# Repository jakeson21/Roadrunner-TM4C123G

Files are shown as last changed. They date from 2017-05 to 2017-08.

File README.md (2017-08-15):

# Roadrunner
Arduino clone based on TI's TM4C123G, an ARM M4F running at 80 MHz.

# Project Goal 
The goal of this project is to build a bridge between Texas Instrument's Tiva™ C LaunchPad, based on the TM4C123GH6PM, and the Arduino form factor. The LaunchPad series of development kits already benefit from an Arduino-like code development environment in the form of Energia, but lack a compatible form factor to make use of the extensive list of shields.

This project aims to merge these two worlds by putting the processing power and integrated peheripherial set of the 80-MHz ARM M4F based TM4C123 series of micro controllers into the Arduino-Leo (and Uno, Duemilanove, Due, *Mega) compatible form factor.
This will provide typical Arduino users with a much more powerful board while maintaining a familiar programming environment (through the use of Energia). It also provides a platform for those wanting to grow beyond this basic development approach into a more low-level IDE by using TI's free Code Composer Studio and selecting the EK-TM4C123GXL project configuration.

*The board breaks out all pins, but only utilizes the basic set of headers to maintain a 2" x 3" form factor.

# Other notable parameters
Most GPIO are 5V tolerant
Peripheral libraries are pre-loaded onto on-board ROM, reducing support code size.
32-bit CPU with single-precision FPU
Single-cycle multiply instruction and hardware divide
16-bit SIMD vector processing unit
Ultra-low power consumption with integrated sleep modes
etc... See datasheet for more information

# Project Planning
✔ Circuit design (using KiCAD). Programming will rely on the use of an EK-TM4C123GXL dev kit by tapping into its target ICDI JTAG headers.

✔ Board layout, including relocating Energia defined pins to their Arduino form factor locations.

✔ Fabrication (sent to OSH Park 4/16/2017)

✔ Board assembly

✔ Create custom board definition for use in Energia

▢ Hardware testing and verification

▢ Mass-production if enough people are interested

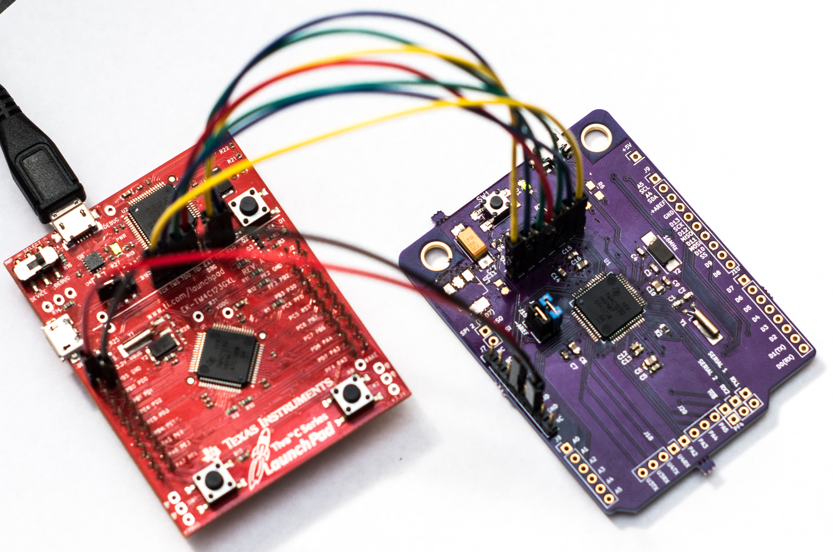
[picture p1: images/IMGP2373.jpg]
board image


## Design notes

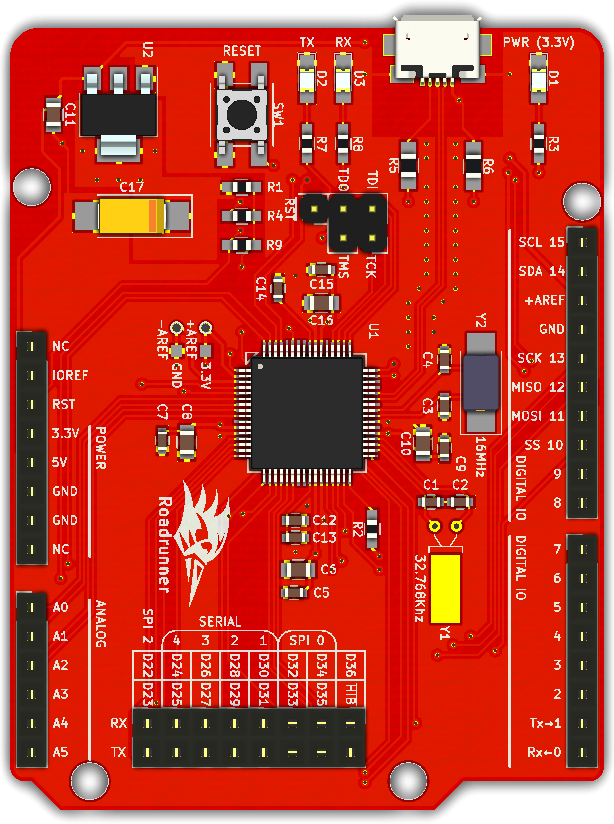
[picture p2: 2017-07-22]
images/Roadrunner_top_v1.1.png

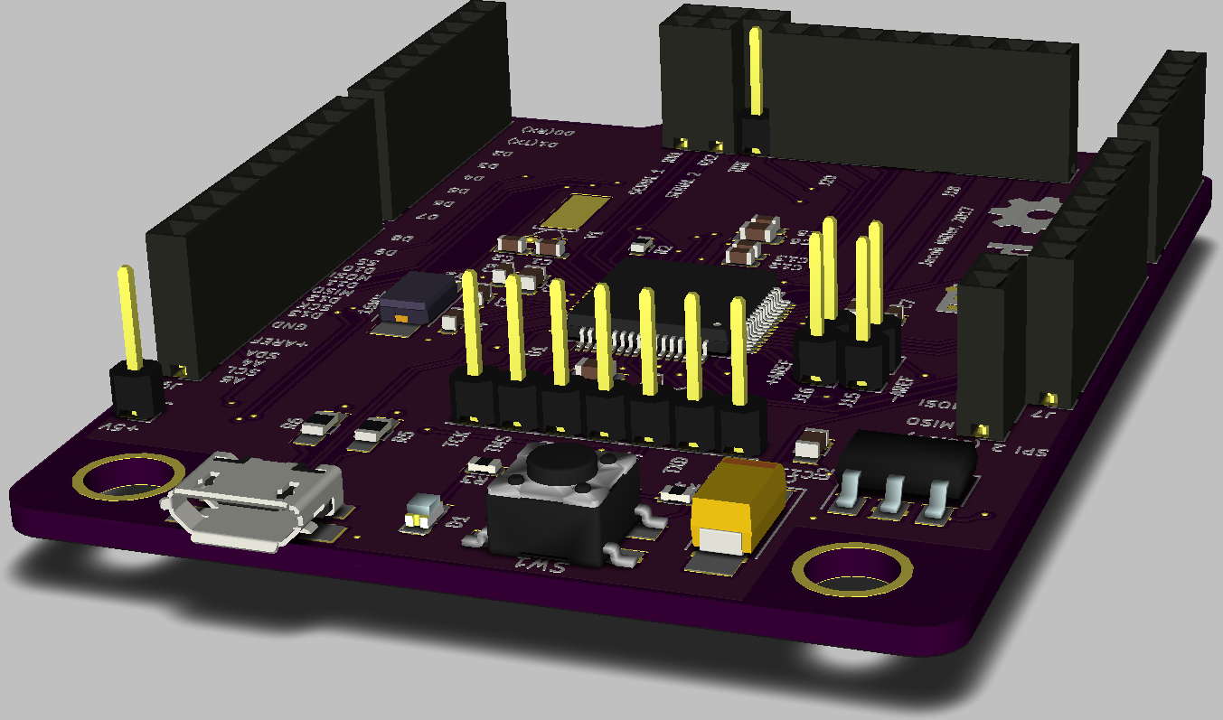
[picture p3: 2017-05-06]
images/Arduino_Leo_Tiva_HiFi_45_osh.png

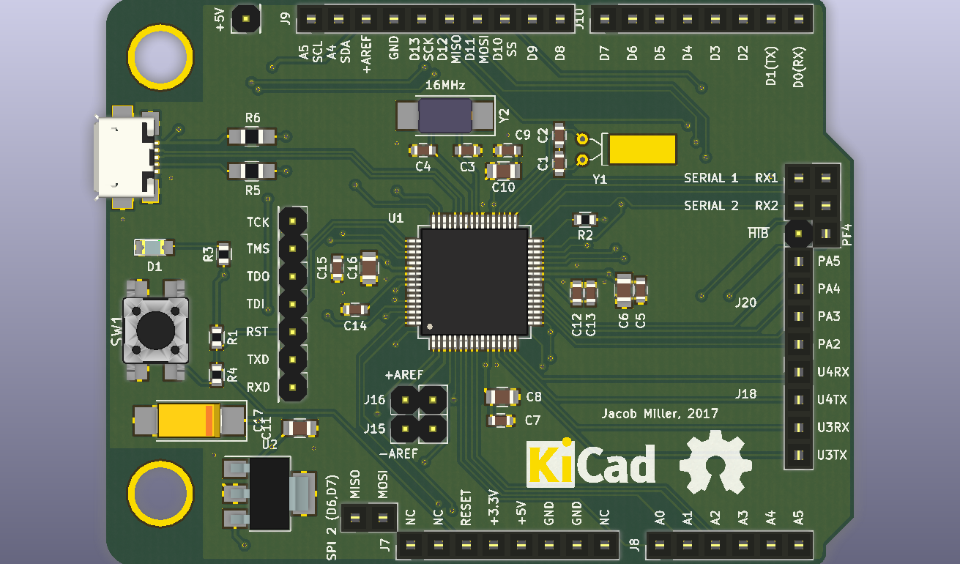
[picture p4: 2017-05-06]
images/Arduino_Leo_Tiva_HiFi_ortho.png

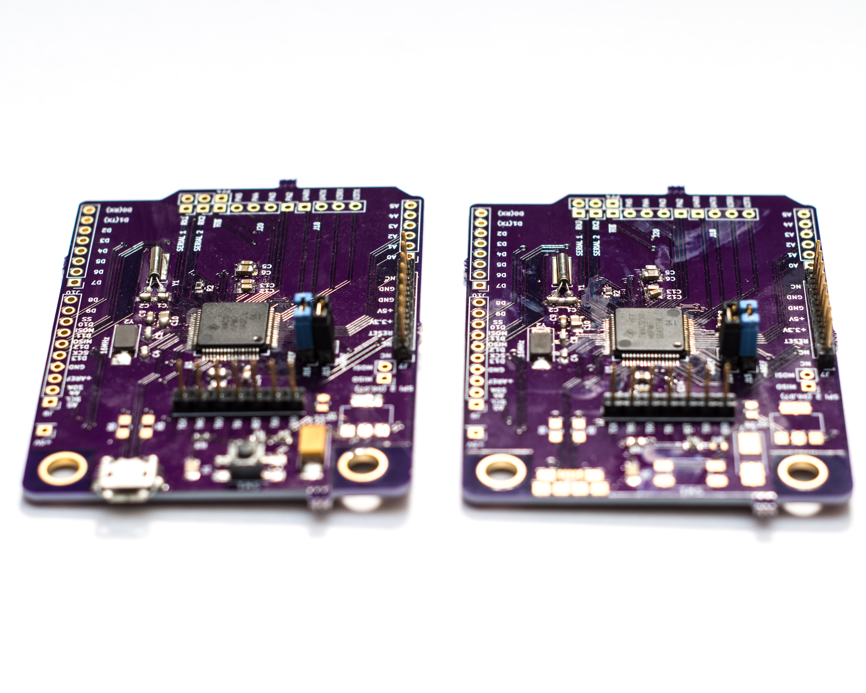
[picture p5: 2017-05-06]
images/IMGP2375.jpg

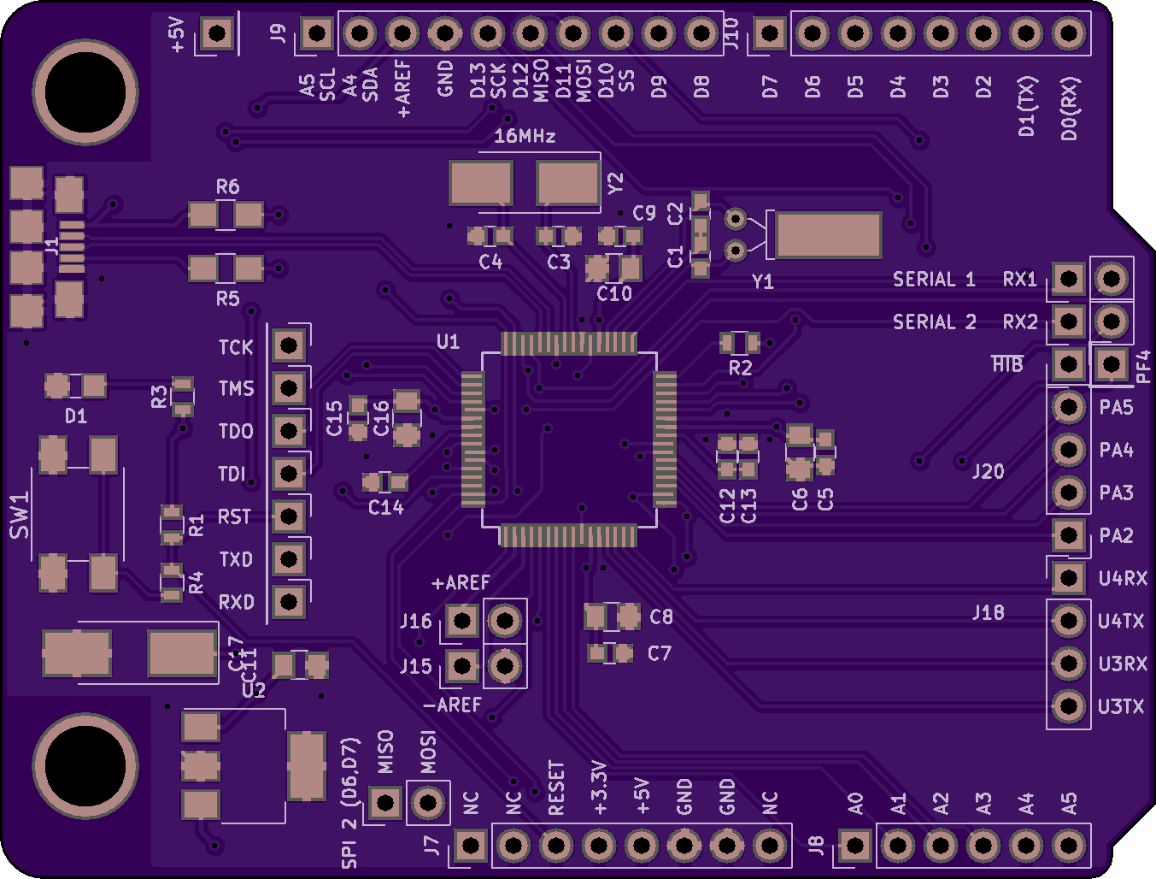
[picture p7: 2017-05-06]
images/osh-park-top.png

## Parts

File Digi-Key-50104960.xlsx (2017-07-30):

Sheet: Sheet1
Index | Quantity | Part Number | Manufacturer Part Number | Description | Customer Reference | Backorder | Unit Price | Extended Price | BOM | Extended Price
1 | 10 | LM1117IMPX-3.3/NOPBCT-ND | LM1117IMPX-3.3/NOPB | IC REG LDO 3.3V 0.8A SOT223 |  | 0 | $0.9270 | $9.27 | 1 | $0.93
2 | 3 | 609-4613-1-ND | 10118192-0001LF | CONN USB MICRO B RECPT SMT R/A |  | 0 | $0.4600 | $1.38 | 1 | $0.46
3 | 10 | 1276-6780-1-ND | CL21A226MOCLRNC | CAP CER 22UF 16V X5R 0805 |  | 0 | $0.1680 | $1.68 | 4 | $0.67
4 | 10 | 490-3296-1-ND | GRM188R61C225KE15D | CAP CER 2.2UF 16V X5R 0603 |  | 0 | $0.0890 | $0.89 | 1 | $0.09
5 | 10 | 475-1410-1-ND | LG R971-KN-1 | LED GREEN DIFFUSED 0805 SMD |  | 0 | $0.1800 | $1.80 | 1 | $0.18
6 | 25 | P10.0KHCT-ND | ERJ-3EKF1002V | RES SMD 10K OHM 1% 1/10W 0603 |  | 0 | $0.0144 | $0.36 | 1 | $0.01
7 | 25 | P1.00MHCT-ND | ERJ-3EKF1004V | RES SMD 1M OHM 1% 1/10W 0603 |  | 0 | $0.0144 | $0.36 | 1 | $0.01
8 | 25 | P100HCT-ND | ERJ-3EKF1000V | RES SMD 100 OHM 1% 1/10W 0603 |  | 0 | $0.0144 | $0.36 | 1 | $0.01
9 | 25 | P75.0HCT-ND | ERJ-3EKF75R0V | RES SMD 75 OHM 1% 1/10W 0603 |  | 0 | $0.0144 | $0.36 | 1 | $0.01
10 | 25 | P51.0HCT-ND | ERJ-3EKF51R0V | RES SMD 51 OHM 1% 1/10W 0603 |  | 0 | $0.0144 | $0.36 | 0 | $0.00
11 | 5 | 732-7003-1-ND | 430181038816 | SWITCH TACTILE SPST-NO 0.05A 12V |  | 0 | $0.3500 | $1.75 | 1 | $0.35
12 | 3 | 300-8763-ND | CFS-20632768HZFB | CRYSTAL 32.7680KHZ 12.5PF T/H |  | 0 | $0.6000 | $1.80 | 1 | $0.60
13 | 3 | 644-1187-1-ND | NX5032GA-16MHZ-STD-CSK-4 | CRYSTAL 16.0000MHZ 8PF SMD |  | 0 | $0.7200 | $2.16 | 1 | $0.72
14 | 3 | 399-3744-1-ND | T491C226K016AT | CAP TANT 22UF 16V 10% 2413 |  | 0 | $0.6600 | $1.98 | 1 | $0.66
15 | 10 | 311-1772-1-ND | CC0603JRNPO9BN240 | CAP CER 24PF 50V C0G/NPO 0603 |  | 0 | $0.0650 | $0.65 | 2 | $0.13
16 | 25 | 399-1049-1-ND | C0603C100J5GACTU | CAP CER 10PF 50V C0G/NP0 0603 |  | 0 | $0.0240 | $0.60 | 2 | $0.05
17 | 25 | 311-1777-1-ND | CC0603JRX7R8BB104 | CAP CER 0.1UF 25V X7R 0603 |  | 0 | $0.0232 | $0.58 | 5 | $0.12
18 | 25 | 490-1536-1-ND | GRM188R61C105KA93D | CAP CER 1UF 16V X5R 0603 |  | 0 | $0.0272 | $0.68 | 1 | $0.03
 |  |  |  |  |  |  | Subtotal | $27.02
 |  |  | TM4C123GH6PMI7 | IC MCU 32BIT 256KB FLASH 64LQFP |  |  | $10.67 | $32.01 | 1 | $10.67
 |  |  |  |  |  |  |  |  |  | Component Subtotal per board
 |  |  |  |  |  |  |  |  |  | $15.71
 |  |  | Fabrication | Description | Quantity | Extended Cost |  |  |  | Cost per board built
 |  |  | OSH-Park | 2.71x2.06 inch (68.73x52.22 mm) 4 layer board. | 3 | $55.60 |  |  |  | $34.24

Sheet: BOM
Manufacturer Part Number | BOM | Unit Price | Extended Price
LM1117IMPX-3.3/NOPB | 1 | $0.9270 | $0.93
10118192-0001LF | 1 | $0.4600 | $0.46
CL21A226MOCLRNC | 4 | $0.1680 | $0.67
GRM188R61C225KE15D | 1 | $0.0890 | $0.09
LG R971-KN-1 | 1 | $0.1800 | $0.18
ERJ-3EKF1002V | 1 | $0.0144 | $0.01
ERJ-3EKF1004V | 1 | $0.0144 | $0.01
ERJ-3EKF1000V | 1 | $0.0144 | $0.01
ERJ-3EKF75R0V | 1 | $0.0144 | $0.01
ERJ-3EKF51R0V | 0 | $0.0144 | $0.00
430181038816 | 1 | $0.3500 | $0.35
CFS-20632768HZFB | 1 | $0.6000 | $0.60
NX5032GA-16MHZ-STD-CSK-4 | 1 | $0.7200 | $0.72
T491C226K016AT | 1 | $0.6600 | $0.66
CC0603JRNPO9BN240 | 2 | $0.0650 | $0.13
C0603C100J5GACTU | 2 | $0.0240 | $0.05
CC0603JRX7R8BB104 | 5 | $0.0232 | $0.12
GRM188R61C105KA93D | 1 | $0.0272 | $0.03
TM4C123GH6PMI7 | 1 | $10.67 | $10.67
 |  |  | $15.71

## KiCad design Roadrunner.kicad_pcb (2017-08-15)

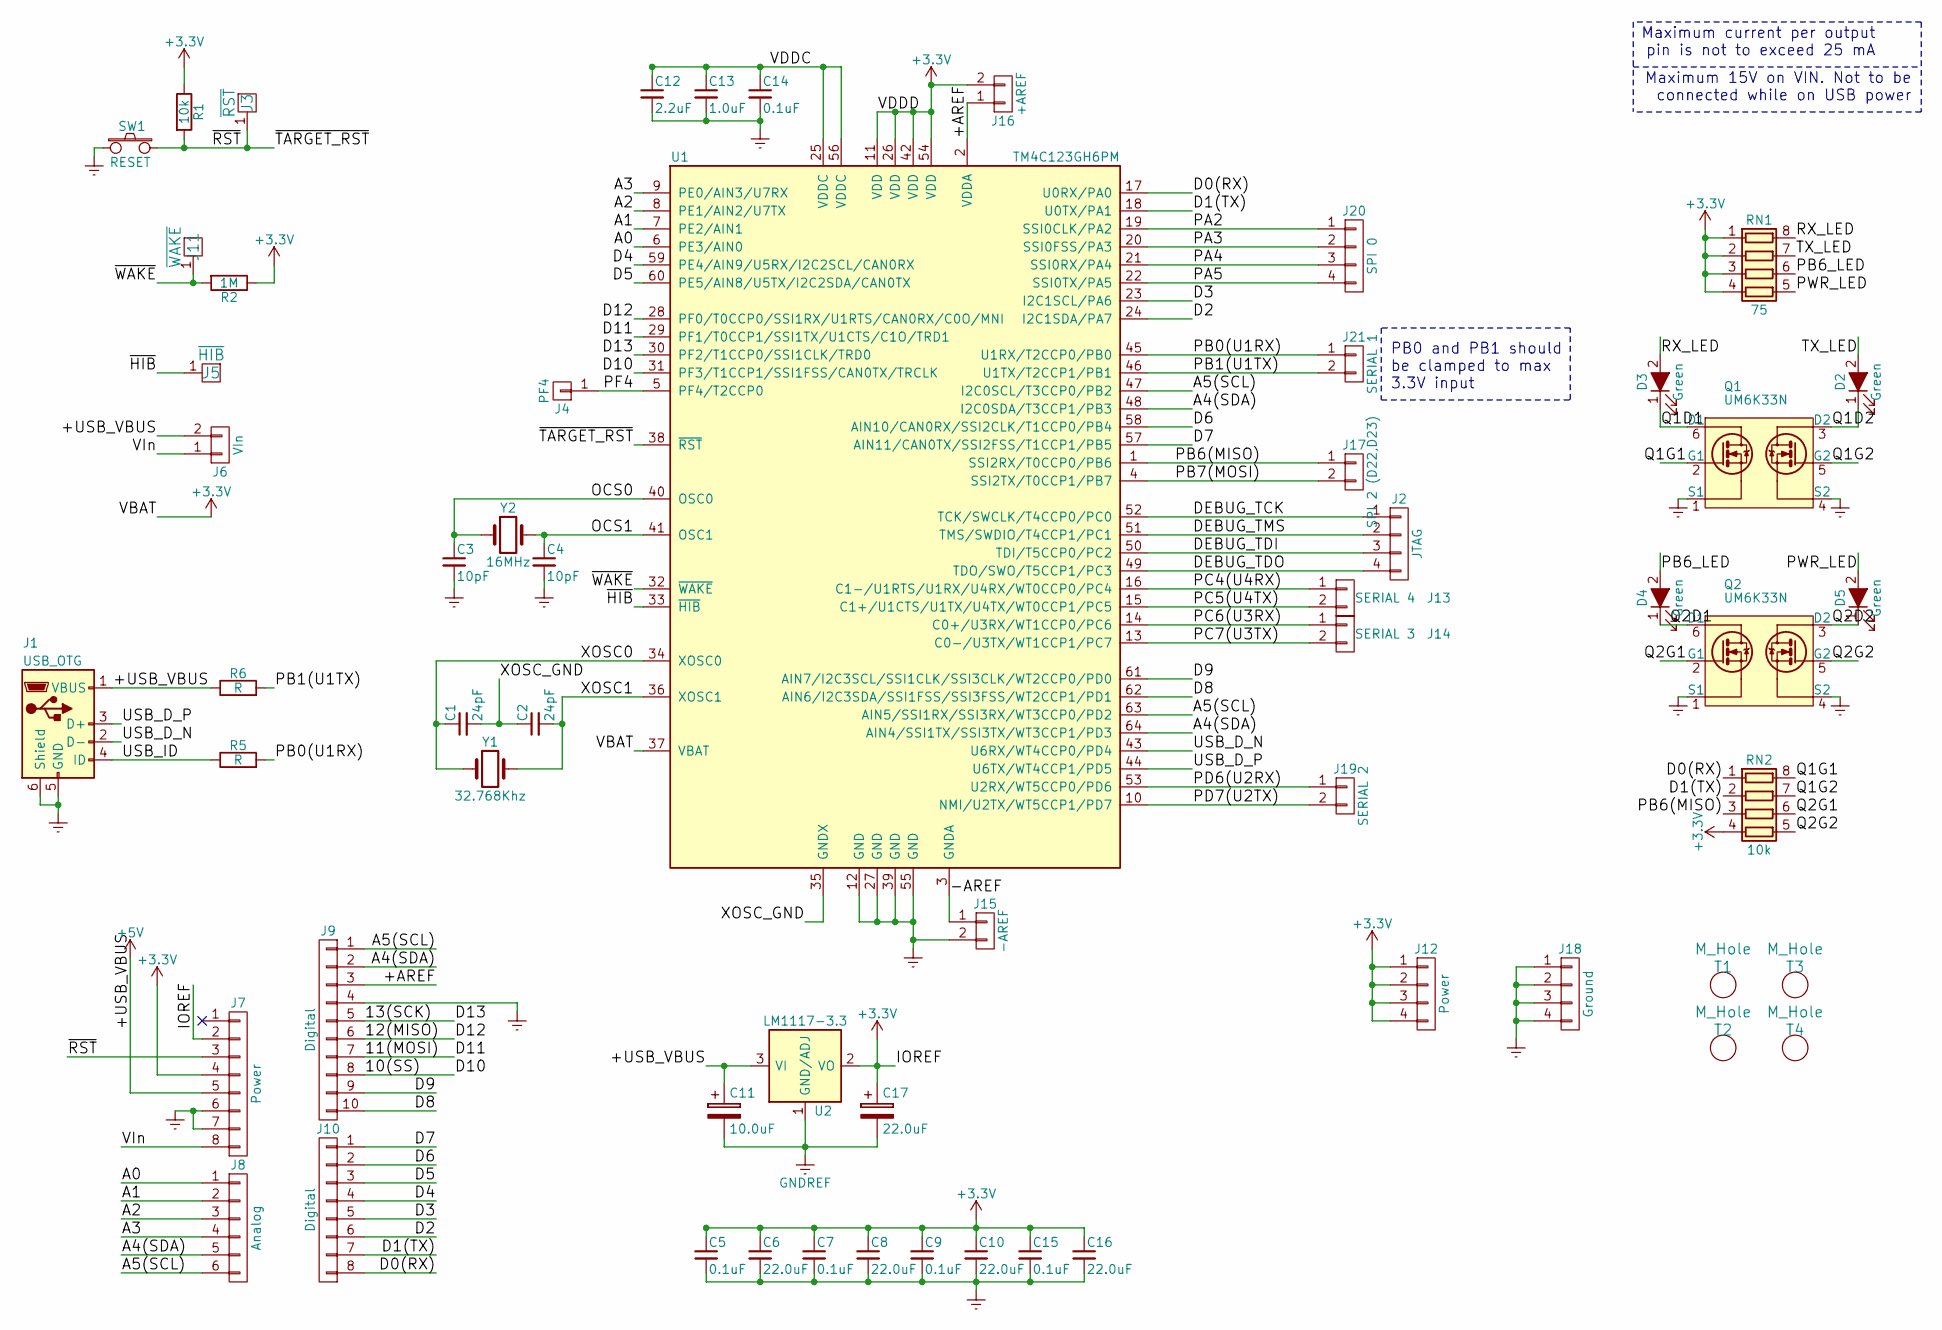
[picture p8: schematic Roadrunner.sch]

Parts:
C1, C2: 24pF; C_0603; Part # CC0603JRNPO9BN240
C3, C4: 10pF; C_0603; Part # C0603C100J5GACTU
C5, C7, C9, C14, C15: 0.1uF; C_0603; Part # CC0603JRX7R8BB104
C6, C8, C10, C16: 22.0uF; C_0805; Part # CL21A226MOCLRNC
C11: 10.0uF; C_0805
C12: 2.2uF; C_0603; Part # GRM188R61C225KE15D
C13: 1.0uF; C_0603; Part # GRM188R61C105KA93D
C17: 22.0uF; CP_Tantalum_Case-C_EIA-6032-28_Hand; Part # T491C226K016AT
D2, D3, D4, D5: Green; LED_0805; Part # LG R971-KN-1
J1: USB_OTG; USB_Micro_B_FCI_10118192; Part # 10118192-0001LF
J2: JTAG; Pin_Header_Straight_2x02_Pitch2.54mm
J3: ~RST; Pin_Header_Straight_1x01_Pitch2.54mm
J4: PF4; Socket_Strip_Straight_1x01_Pitch2.54mm
J5: ~HIB; Socket_Strip_Straight_1x01_Pitch2.54mm
J6: VIn; NetTie-I_Connected_SMD
J7: Power; Socket_Strip_Straight_1x08_Pitch2.54mm
J8: Analog; Socket_Strip_Straight_1x06_Pitch2.54mm
J9: Digital; Socket_Strip_Straight_1x10_Pitch2.54mm
J10: Digital; Socket_Strip_Straight_1x08_Pitch2.54mm
J11: ~WAKE; Socket_Strip_Straight_1x01_Pitch2.54mm
J12: Power; Socket_Strip_Straight_1x04_Pitch2.54mm
J13: SERIAL 4; Socket_Strip_Straight_1x02_Pitch2.54mm
J14: SERIAL 3; Socket_Strip_Straight_1x02_Pitch2.54mm
J15: -AREF; NetTie-I_Connected_SMD
J16: +AREF; NetTie-I_Connected_SMD
J17: SPI 2 (D22,D23); Socket_Strip_Straight_1x02_Pitch2.54mm
J18: Ground; Socket_Strip_Straight_1x04_Pitch2.54mm
J19: SERIAL 2; Socket_Strip_Straight_1x02_Pitch2.54mm
J20: SPI 0; Socket_Strip_Straight_2x02_Pitch2.54mm
J21: SERIAL 1; Socket_Strip_Straight_1x02_Pitch2.54mm
Q1, Q2: UM6K33N; SOT-363_SC-70-6; Part # UM6K33NTN
R1: 10k; R_0603_HandSoldering; Part # RC0603FR-0710KL
R2: 1M; R_0603_HandSoldering; Part # RCG06031M00FKEA
R5, R6: R; R_0805_HandSoldering
RN1: 75; YC164-JR-0775RL; Part # YC164-JR-0775RL
RN2: 10k; YC164-JR-0775RL; Part # EXB-38V103JV
SW1: RESET; SW_SPST_WS-TASV_4.5x4.5mm; Part # 430181038816
T1, T2, T3, T4: M_Hole; ArduinoMountingHole_3.2mm
U1: TM4C123GH6PM; LQFP-64_10x10mm_Pitch0.5mm; Part # TM4C123GH6PMI7
U2: LM1117-3.3; SOT-223; Part # LM1117IMPX-3.3/NOPB
Y1: 32.768Khz; Crystal_C26-LF_d2.1mm_l6.5mm_Horizontal_1EP_style1; Part # CFS-20632768HZFB
Y2: 16MHz; Crystal_SMD_5032-2pin_5.0x3.2mm_HandSoldering; Part # NX5032GA-16MHZ-STD-CSK-4

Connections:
+3V3: C5.1, C6.1, C7.1, C8.1, C9.1, C10.1, C15.1, C16.1, C17.1, J7.2, J7.4, J12.1, J12.2, J12.3, J12.4, J16.2, R1.1, R2.1, RN1.1 (R1.1), RN1.2 (R2.1), RN1.3 (R3.1), RN1.4 (R4.1), RN2.4 (R4.1), U1.11 (VDD), U1.26 (VDD), U1.37 (VBAT), U1.42 (VDD), U1.54 (VDD), U2.2 (VO), U2.4 (VO)
+5V: C11.1, J1.1 (VBUS), J6.2, J7.5, R6.1, U2.3 (VI)
/10(SS): J9.8, U1.31 (PF3/T1CCP1/SSI1FSS/CAN0TX/TRCLK)
/11(MOSI): J9.7, U1.29 (PF1/T0CCP1/SSI1TX/U1CTS/C1O/TRD1)
/12(MISO): J9.6, U1.28 (PF0/T0CCP0/SSI1RX/U1RTS/CAN0RX/C0O/MNI)
/13(SCK): J9.5, U1.30 (PF2/T1CCP0/SSI1CLK/TRD0)
/+AREF: J9.3, J16.1, U1.2 (VDDA)
/-AREF: J15.1, U1.3 (GNDA)
/A0: J8.1, U1.6 (PE3/AIN0)
/A1: J8.2, U1.7 (PE2/AIN1)
/A2: J8.3, U1.8 (PE1/AIN2/U7TX)
/A3: J8.4, U1.9 (PE0/AIN3/U7RX)
/A4(SDA): J8.5, J9.2, U1.48 (I2C0SDA/T3CCP1/PB3), U1.64 (AIN4/SSI1TX/SSI3TX/WT3CCP1/PD3)
/A5(SCL): J8.6, J9.1, U1.47 (I2C0SCL/T3CCP0/PB2), U1.63 (AIN5/SSI1RX/SSI3RX/WT3CCP0/PD2)
/D0(RX): J10.8, RN2.1 (R1.1), U1.17 (U0RX/PA0)
/D1(TX): J10.7, RN2.2 (R2.1), U1.18 (U0TX/PA1)
/D2: J10.6, U1.24 (I2C1SDA/PA7)
/D3: J10.5, U1.23 (I2C1SCL/PA6)
/D4: J10.4, U1.59 (PE4/AIN9/U5RX/I2C2SCL/CAN0RX)
/D5: J10.3, U1.60 (PE5/AIN8/U5TX/I2C2SDA/CAN0TX)
/D6: J10.2, U1.58 (AIN10/CAN0RX/SSI2CLK/T1CCP0/PB4)
/D7: J10.1, U1.57 (AIN11/CAN0TX/SSI2FSS/T1CCP1/PB5)
/D8: J9.10, U1.62 (AIN6/I2C3SDA/SSI1FSS/SSI3FSS/WT2CCP1/PD1)
/D9: J9.9, U1.61 (AIN7/I2C3SCL/SSI1CLK/SSI3CLK/WT2CCP0/PD0)
/DEBUG_TCK: J2.1, U1.52 (TCK/SWCLK/T4CCP0/PC0)
/DEBUG_TDI: J2.3, U1.50 (TDI/T5CCP0/PC2)
/DEBUG_TDO: J2.4, U1.49 (TDO/SWO/T5CCP1/PC3)
/DEBUG_TMS: J2.2, U1.51 (TMS/SWDIO/T4CCP1/PC1)
/OCS0: C3.1, U1.40 (OSC0), Y2.1
/OCS1: C4.1, U1.41 (OSC1), Y2.2
/PA2: J20.1, U1.19 (SSI0CLK/PA2)
/PA3: J20.2, U1.20 (SSI0FSS/PA3)
/PA4: J20.3, U1.21 (SSI0RX/PA4)
/PA5: J20.4, U1.22 (SSI0TX/PA5)
/PB0(U1RX): J21.1, R5.2, U1.45 (U1RX/T2CCP0/PB0)
/PB1(U1TX): J21.2, R6.2, U1.46 (U1TX/T2CCP1/PB1)
/PB6(MISO): J17.1, RN2.3 (R3.1), U1.1 (SSI2RX/T0CCP0/PB6)
/PB6_LED: D4.2 (A), RN1.6 (R3.2)
/PB7(MOSI): J17.2, U1.4 (SSI2TX/T0CCP1/PB7)
/PC4(U4RX): J13.1, U1.16 (C1-/U1RTS/U1RX/U4RX/WT0CCP0/PC4)
/PC5(U4TX): J13.2, U1.15 (C1+/U1CTS/U1TX/U4TX/WT0CCP1/PC5)
/PC6(U3RX): J14.1, U1.14 (C0+/U3RX/WT1CCP0/PC6)
/PC7(U3TX): J14.2, U1.13 (C0-/U3TX/WT1CCP1/PC7)
/PD6(U2RX): J19.1, U1.53 (U2RX/WT5CCP0/PD6)
/PD7(U2TX): J19.2, U1.10 (NMI/U2TX/WT5CCP1/PD7)
/PF4: J4.1, U1.5 (PF4/T2CCP0)
/PWR_LED: D5.2 (A), RN1.5 (R4.2)
/Q1D1: D3.1 (K), Q1.6 (D1)
/Q1D2: D2.1 (K), Q1.3 (D2)
/Q1G1: Q1.2 (G1), RN2.8 (R1.2)
/Q1G2: Q1.5 (G2), RN2.7 (R2.2)
/Q2D1: D4.1 (K), Q2.6 (D1)
/Q2D2: D5.1 (K), Q2.3 (D2)
/Q2G1: Q2.2 (G1), RN2.6 (R3.2)
/Q2G2: Q2.5 (G2), RN2.5 (R4.2)
/RX_LED: D3.2 (A), RN1.8 (R1.2)
/TX_LED: D2.2 (A), RN1.7 (R2.2)
/USB_D_N: J1.2 (D-), U1.43 (U6RX/WT4CCP0/PD4)
/USB_D_P: J1.3 (D+), U1.44 (U6TX/WT4CCP1/PD5)
/USB_ID: J1.4 (ID), R5.1
/VDDC: C12.1, C13.1, C14.1, U1.25 (VDDC), U1.56 (VDDC)
/VIn: J6.1, J7.8
/XOSC0: C1.1, U1.34 (XOSC0), Y1.1
/XOSC1: C2.2, U1.36 (XOSC1), Y1.2
/XOSC_GND: C1.2, C2.1, U1.35 (GNDX)
/~HIB: J5.1, U1.33 (~HIB~)
/~RST: J3.1, J7.3, R1.2, SW1.2, U1.38 (~RST~)
/~WAKE: J11.1, R2.2, U1.32 (~WAKE~)
GNDREF: C3.2, C4.2, C5.2, C6.2, C7.2, C8.2, C9.2, C10.2, C11.2, C12.2, C13.2, C14.2, C15.2, C16.2, C17.2, J1.5 (GND), J1.6 (Shield), J7.6, J7.7, J9.4, J15.2, J18.1, J18.2, J18.3, J18.4, Q1.1 (S1), Q1.4 (S2), Q2.1 (S1), Q2.4 (S2), SW1.1, U1.12 (GND), U1.27 (GND), U1.39 (GND), U1.55 (GND), U2.1 (GND/ADJ)

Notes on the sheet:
PB0 and PB1 should be clamped to max 3.3V input
Maximum current per output pin is not to exceed 25 mA
Maximum 15V on VIN. Not to be connected while on USB power

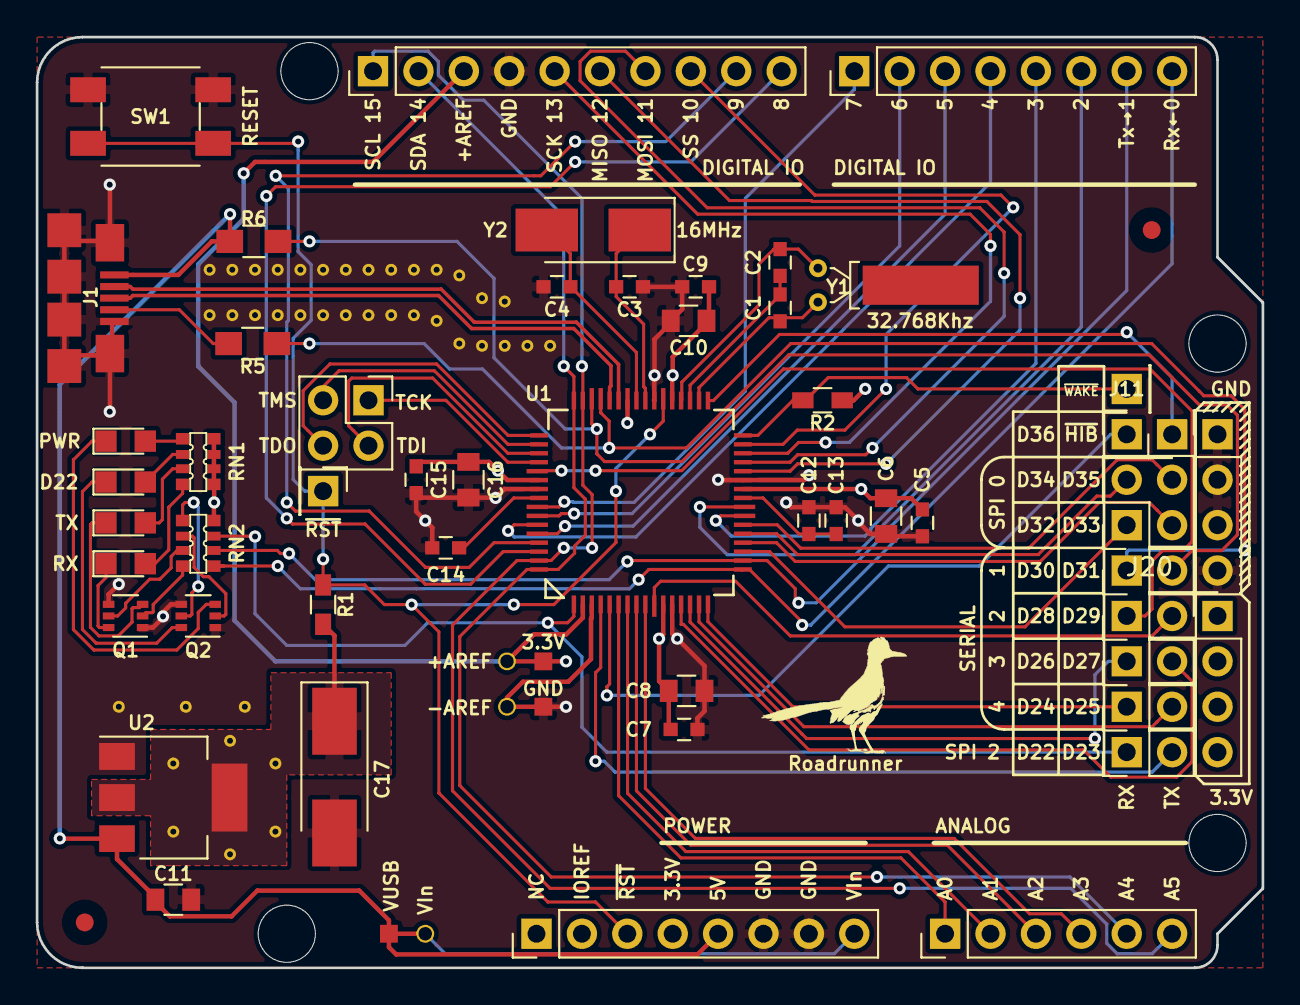
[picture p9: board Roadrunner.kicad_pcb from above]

Board: 4 copper layers, 68.6 x 52.1 mm, 61 parts (0 on the bottom side), 69 nets.

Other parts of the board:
RoadrunnerLogoMedium: G***; RoadrunnerLogoMedium
RoadrunnerLogoSmall: G***; RoadrunnerLogoSmall

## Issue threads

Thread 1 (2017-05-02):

Wrong footprint for LM1117 3.3

jakeson21, 2017-05-02:
Swap the regulator component in circuit diagram for LM1117 3.3. A generic regulator was used in the circuit diagram initially and it was never changed to the actual part used in the BOM.

jakeson21, 2017-05-09:
Incorrect footprint replaced with LM1117-3.3 footprint and schematic part.

Closed 2017-05-09.

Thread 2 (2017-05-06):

Mods to LEGO Mounting Holes

jakeson21, 2017-05-06:
Remove LEGO holes. Replace with standard Arduino size and locations.
Enlarge hole by 0.5 mm.

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

Closed 2017-08-17.

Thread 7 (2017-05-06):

Swap UART Labels on D0,D1

jakeson21, 2017-05-06:
Should read
D0 = Tx
D1 = Rx

jakeson21, 2017-05-09:
Issue fixed in commit 904a74cad999999ad7d842ee346f2c83043d03ba.
Fixed incorrect pin labels in schematic. Rerouted signals to correct pins.

Closed 2017-05-09.

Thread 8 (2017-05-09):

Add ICDI Pull-up Resistors

jakeson21, 2017-05-09:
Add pull-ups to ICDI lines so board can be used as a programmer.

jakeson21, 2017-07-09:
OBE via documentation:

System Design Guidelines for the TM4C123x Family of
Tiva™ C Series Microcontrollers

Tiva™ C Series microcontrollers have default internal pull-up resistors on TCK, TMS, TDI, and TDO
signals. External pull-up resistors are not required if these connections are kept short. If the JTAG signals
are greater than 2 in. (51 mm) or routed near an area where they could pick up noise, TCK should be
externally pulled-up with a 10K or stronger resistor or pulled-down with a 1K or stronger resistor to prevent any transitions that could unexpectedly execute a JTAG instruction.

Closed 2017-07-09.

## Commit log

2017-04-17 Version 1.0 - Sent to OSH Park 4/16/2017
    [Arduino_Leo_Tiva.kicad_pcb, Arduino_Leo_Tiva.sch, PinMap.xlsx]
2017-04-17 Added as-built Mfg. part numbers and full descriptions to each component.
    [Arduino_Leo_Tiva.kicad_pcb, Arduino_Leo_Tiva.sch]
2017-04-19 Added KiCAD silkscreen and name to top layer
    [Arduino_Leo_Tiva.kicad_pcb]
2017-05-06 Fixed issue with incorrect schematic symbol and footprint for 3.3V regulator IC. Fixed typo in path
    [Arduino_Leo_Tiva.kicad_pcb, Arduino_Leo_Tiva.sch, PinMap.xlsx]
2017-05-09 Fixed "Swap UART Labels on D0,D1 #7"
    Had U0Tx and U0Rx labled incorrectly in schematic.
    Fixed labels and rerouted signals to correct pins.
    [Arduino_Leo_Tiva.kicad_pcb, Arduino_Leo_Tiva.sch, PinMap.xlsx]
2017-05-09 Modified LEGO mounting hole - Increased width by 0.05 mm - Removed through hole plating (now NPTH)
    [Arduino_Leo_Tiva.kicad_pcb, Arduino_Leo_Tiva.sch]
2017-07-22 Major changes to board layout and design leading towards revisoin v1.1
    [Arduino_Leo_Tiva.kicad_pcb, Arduino_Leo_Tiva.sch]
2017-07-30 Recent modifications to layout. Switching to resistor arrays. Adding Roadrunner image.
    [Arduino_Leo_Tiva.kicad_pcb, Arduino_Leo_Tiva.sch, Digi-Key-50104960.xlsx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]
2017-08-15 Renaming project ro Roadrunner
    Also include various routing changes and a new logo
    [Roadrunner.kicad_pcb, Roadrunner.sch]
2017-08-15 Added additional 3.3V x4 and GND x4 headers to rear of board
    [Roadrunner.kicad_pcb, Roadrunner.sch]
